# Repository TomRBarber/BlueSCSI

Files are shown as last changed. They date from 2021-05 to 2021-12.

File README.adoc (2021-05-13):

# BlueSCSI
:toc: macro

BlueSCSI & ArdSCSino are hardware that reproduces SCSI devices (hard disks) with an Arduino STM32F103C (aka Blue Pill.)

`BlueSCSI` created by https://github.com/erichelgeson[erichelgeson] is a fork of `ArdSCSino-stm32` which adds:

* Usability Improvements
* Mac specific functionality
* Enable/Disable Passive SCSI termination
* An alternative power source if not able to be powered by the SCSI bus
* Documentation
* Open Hardware (KiCad & Grebers)

`ArdSCSino-stm32` created by https://github.com/ztto/ArdSCSino-stm32[ztto] is the STM32 version of `ArdSCSino`

`ArdSCSino` created by https://twitter.com/h_koma2[Tambo (TNB Seisakusho)]




Join us in #bluescsi on https://discord.gg/GKcvtgU7P9[Discord] or open an issue on this repo.

toc::[]

## Compatibility

If your computer is not listed below - it may be compatible but there is no guarantee it will work. This device is designed and tested to work with pre-PowerPC Macs.

### Compatible

#### Tested by Me

SE, SE/30, Classic, Classic II, Mac II's, Color Classic, LC I/II/III, LC 475, LC 575

#### Partially Compatible

Mac Plus (1.0-c and above) - Only System 7 currenty works.

PowerPC - Some have had luck booting but is not recommended.

#### Reported by others

https://68kmla.org/forums/topic/61045-arduino-scsi-device-work-in-progress/?do=findComment&comment=663077[IIcx], https://68kmla.org/forums/topic/61045-arduino-scsi-device-work-in-progress/?do=findComment&comment=664446[PowerBook 100 (with custom adapter)]

## Performance

Tested on a Color Classic with https://macintoshgarden.org/apps/scsi-director-pro-40[SCSI Director Pro 4]
```
1024KB/Sec Write
900KB/Sec Read
1.01ms Seek
```

## Assembly

++++
See <a href="docs/assembly.md">docs/assembly.md</a>
++++

## Usage

Hard Disk image files are placed in the root directory of a `ExFat` or `FAT32` formatted SD card. https://twitter.com/theory_retro/status/1376571371694723076[`ExFat` may be much faster]. Use a premade or blank disk below. These images are compatible with the RaSCSI device and Basilisk II emulator.

The naming convention is as follows (file name max 32 characters). Note you may mount multiple drives at a time to different SCSI ID's.

`HDxy_512.hda`
```
HD - Hard Disk
x - SCSI ID to attach to. 0-7 (though 7 on a Macintosh is the System)
y - LUN id usually 0. 
512 - Sector size. Usually 512. 256, 512, & 1024 supported.
```

### Examples

`HD10_512.hda` - Hard Disk at SCSI ID 1, LUN 0, sector size of 512.

`HD51_512 System 6.0.8L LC.hda` - Hard Disk at SCSI ID 5, LUN 1, sector size of 512. Text between block size and .hda is ignored.

#### Bad 

`HD99_712 foo bar fizz buzz bang.hda` Over 32 chars and invalid SCSI/LUN/Block size

If no image files are found PC13 will pulse on and off. Check the LOG.txt on the root of the SD card for any errors.

### Premade Images

Premade images are handy to just drop onto your SD card and go. You can use an emulator such as https://www.emaculation.com/doku.php/basiliskii_osx_setup[Basilisk II] on your modern machine to get software from places like the https://macintoshgarden.com[Macintosh Garden] to your vintage mac.

* Premade from RaSCSI in BlueSCSI too - Rename the files based on the Usage instructions above. - http://macintoshgarden.org/apps/rascsi-68kmla-edition

### Blanks

These are blank, formatted drives. If you want to install an OS or software on an empty drive, use one of these.

* Preformatted HFS blank images in various sizes - https://github.com/erichelgeson/BlueSCSI/tree/main/docs/MacHD.zip

### Custom Disk Images (Advanced)

This technique is useful when you would like a disk image larger than the pre-built images in the previous section.

The following instructions demonstrates the process using https://ss64.com/osx/dd.html[dd] on a modern Mac:

1. Open terminal.
2. The following command will create a blank disk image. You can modify the command to suit your use.
   * `dd if=/dev/zero of=example.hda bs=1m count=500`
   * The `count` field defines the number of megabytes (`bs=1m`) the total disk image should be.
   * The output file from the command is "example.hda". This can be changed in the `of=example.hda` field.
3. Place the new blank disk image in the root directory of your SD card.
4. If you do not already have a tool to format SCSI drives, https://macintoshgarden.org/apps/lido-756[download LIDO]. You can use an emulator such as https://www.emaculation.com/doku.php/basiliskii_osx_setup[Basilisk II] to move files to the image to prepare your installation.
5. After booting into your target machine with the working Mac OS disk image on your BlueSCSI from step 3, format the blank disk.

### Termination

To enable termination place the two jumpers on the TERM block. Termination should be enabled if it is the last device in the SCSI chain, otherwise remove the jumpers if it is not.

## Troubleshooting

If you assembled it yourself, either through a kit or by sourcing the parts yourself, link:docs/troubleshooting-Kit.adoc[start here]

If you purchased a pre-assembled kit, or have already gone through the hardware troubleshooting steps, link:docs/troubleshooting-assembled.adoc[start here]

## Hardware Versions

### 1.1-a (in testing)

* Other SCSI connection types
* More silk screen art

### 1.0-c (Latest)

* Fixed issue with diode footprint being too small
* Fixed issue with external power and `TERMPOWER`

### 1.0-b

First release

## Development (Advanced)

Below is for users who wish to edit or develop on the BluePill - normal users should not need to worry about this.

### Setup PlatformIO IDE

Open the project in https://platformio.org/platformio-ide[PlatformIO IDE] and everything is pre-configured.

## Flashing

When flashing you have two options:

Flash by setting up the IDE and re-compiling and programming. If you are a developer and plan to contribute this method is what you should use.

You may also flash the `.bin` file directly from https://www.st.com/en/development-tools/stm32cubeprog.html[STM32CubeProgrammer]. Use this method if you are not a developer and just wish to get the code to the BluePill.

### Using STLink v2 (prefered)

1. Remove SD Card
2. Make sure the STLink is up to date - https://www.st.com/en/development-tools/stsw-link007.html[Latest Firmware]
3. Connect pins `SWDIO`(2), `GND`(4), `SWCLK`(6), and `3.3v`(8) from the programmer to the Blue Pill. NOTE: These are not the same as Serial ports.
4. Run the https://docs.platformio.org/en/latest/integration/ide/vscode.html#project-tasks[PlatformIO: Upload] task.
5. You should see the LED `PC_13` flashing indicating no SD Card detected.
6. Insert SD Card, boot on your favorite Mac!

The following YoutTube video demonstrates the steps of flashing & updating your BlueSCSI https://www.youtube.com/watch?v=bRLAOts_MTM

#### Trouble Shooting

If the device is not detected you may need to hold reset, click program, once it is detected release reset.

If you are unable to get the device in DFU mode for programming you may need to use https://www.st.com/en/development-tools/stm32cubeprog.html[STM32CubeProgrammer] to erase the chip.

### Alterantive upload methods

See the https://docs.platformio.org/en/latest/boards/ststm32/bluepill_f103c8.html#uploading[uploading] documentation on PlatformIO for alterantives.

### Using USB HID

Note: I have not been able to get this method to work. Please contribute to this document if you do.

## Notes

### Making Gerbers for JLCPCB

https://support.jlcpcb.com/article/44-how-to-export-kicad-pcb-to-gerber-files

BlueSCSI(TM) - Eric Helgeson - All rights reserved.

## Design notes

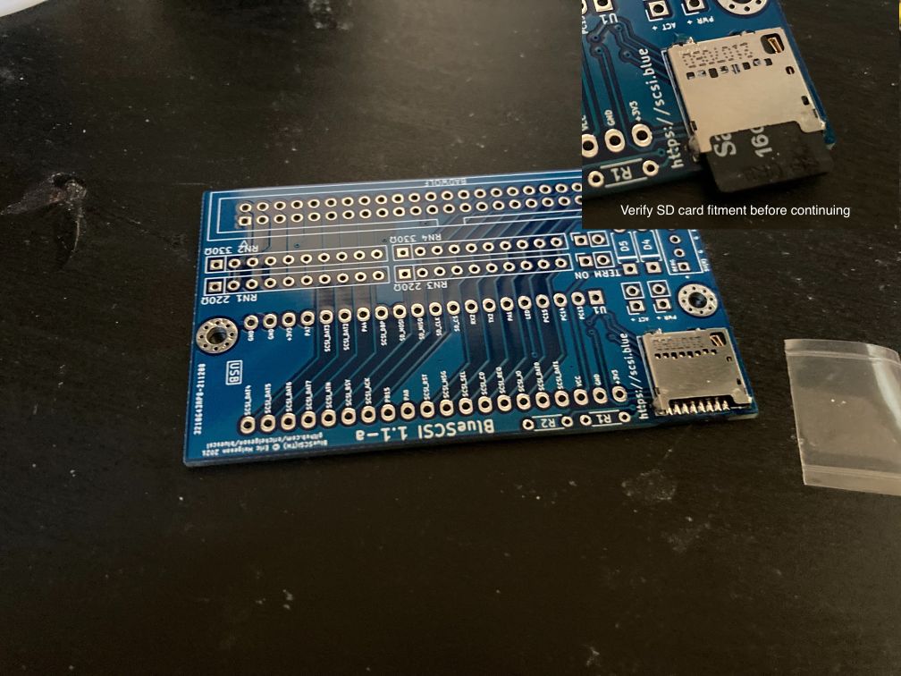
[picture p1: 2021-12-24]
docs/images/DesktopSDSlot.jpg

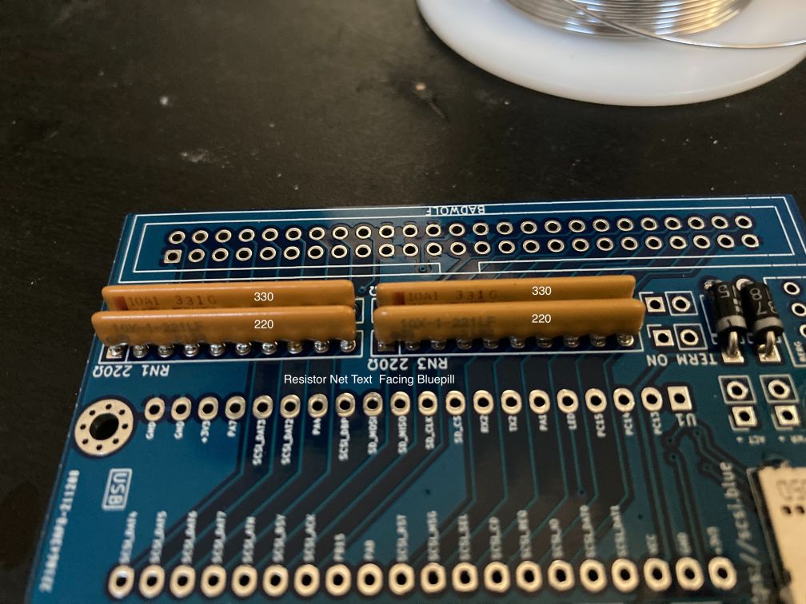
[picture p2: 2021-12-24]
docs/images/DesktopOrientation.jpg

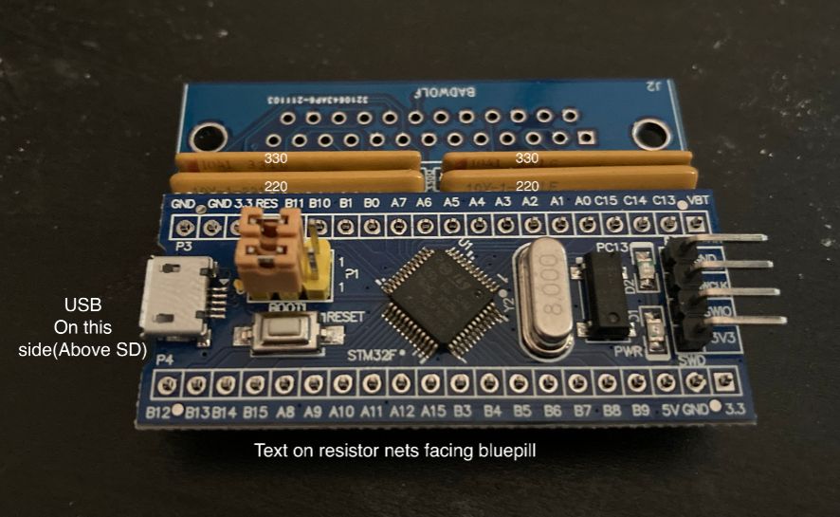
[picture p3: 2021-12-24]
docs/images/DB25-Orientation.jpg

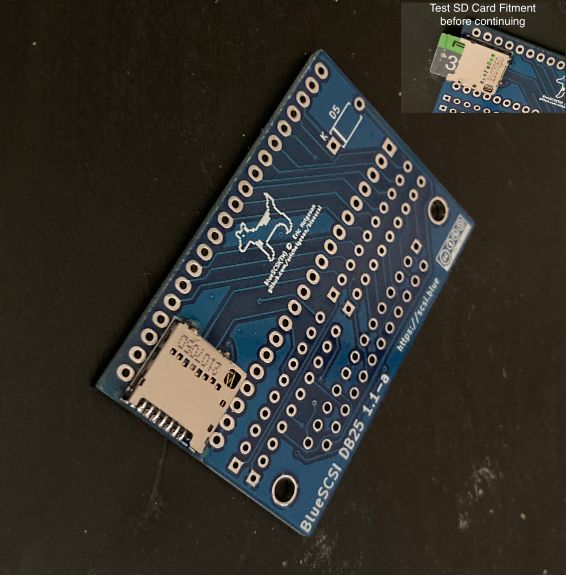
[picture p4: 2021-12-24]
docs/images/DB25 SD Slot.jpg

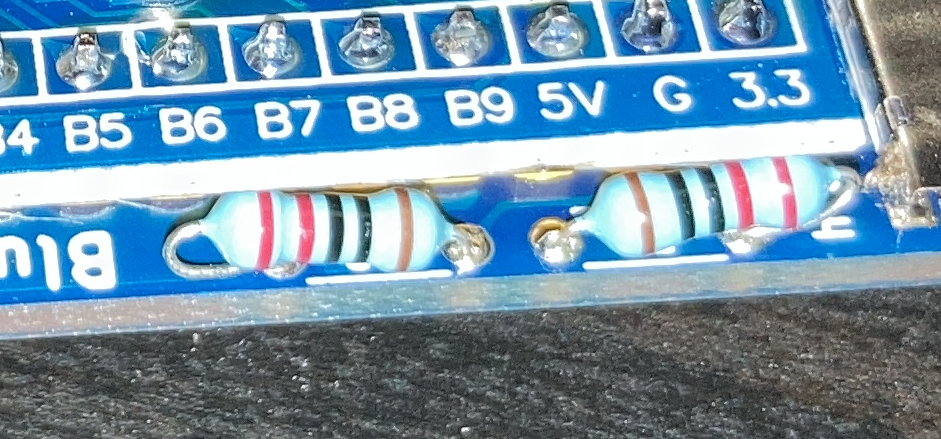
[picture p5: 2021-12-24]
docs/images/DesktopResistorFitment.png

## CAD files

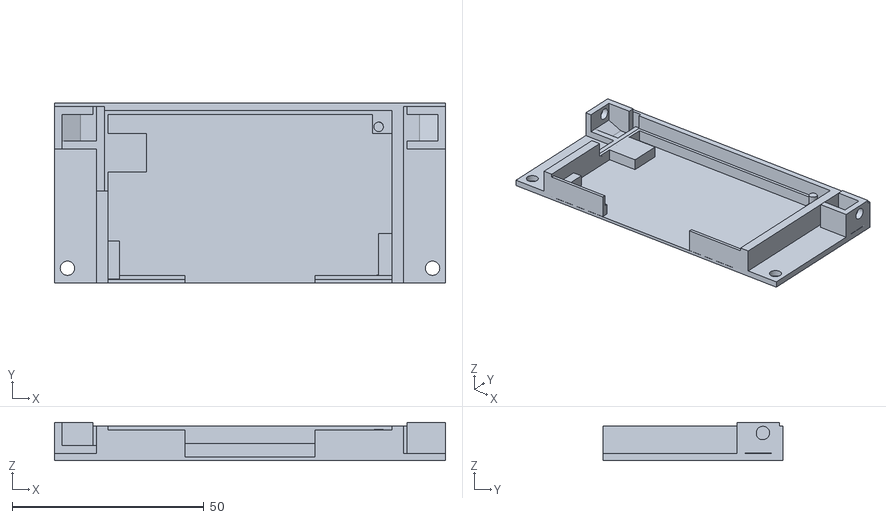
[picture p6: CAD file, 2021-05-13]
3D-Files/bluescsibracket-2.stl
102.0 x 47.0 x 10.0

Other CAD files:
3D-Files/BlueSCSI-1.0-b_V3.stl

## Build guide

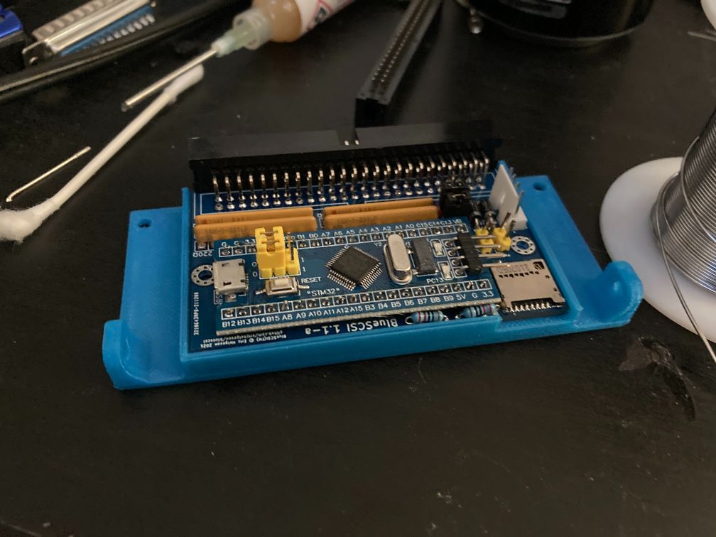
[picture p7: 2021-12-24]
docs/images/DesktopASsembledInCase.jpg

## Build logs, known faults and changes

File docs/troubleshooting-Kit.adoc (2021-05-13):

# Troubleshooting(Kit)

## General:

  * Do not adjust any jumpers on the BluePill microcontroller itself(the 2 near the USB port).  Those are used for programming the device and can potentially erase the memory

  * Double check solder connections.  Ensure no solder bridges, cold or broken solder joints, bad solder connections, etc.  If in doubt, can’t hurt to touch it up.

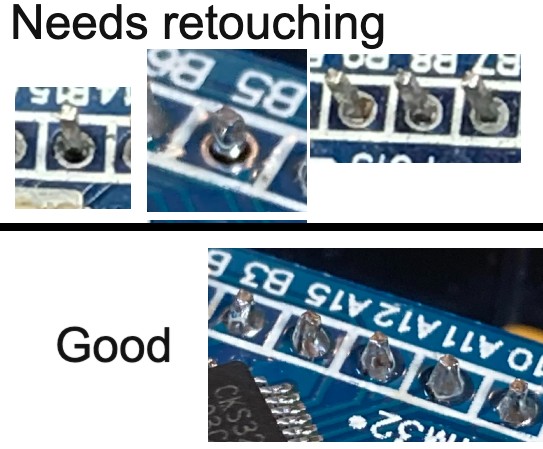
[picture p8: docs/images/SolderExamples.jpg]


  * Make sure Resistor networks are facing the correct way, and the Bluepill is inserted onto the board with the USB next to the SD.



  * Check the chip on the Bluepill itself, make sure no solder balls or anything(If there are, sometimes you can just knock them off with a small screwdriver or toothpick, sometimes you'll need to use an iron and flux/wick)
  


  * Clean any excess flux on the board,  even if it says no-clean.  Sometimes that can cause issues.  Rubbing alcohol and a toothbrush is usually a good solution.

  * Make sure your termination is set correctly.  If it’s the last device on the SCSI chain, you must have termination enabled by having the 2 jumpers on the BlueSCSI board near the SCSI port and resistor networks.

  * Make sure there are no conflicting SCSI IDs. If possible, remove any other SCSI devices.

  * If you have another computer to try it on, give it a try on there.

## No Power:
Most computers should provide SCSI termination power through the SCSI cable, which is enough to power the Bluepill(Mac Plus is a known exception unless you do a mod), but it’s entirely possible a computer doesn’t for whatever reason.   Unplug the BlueSCSI from the computer’s SCSI Connection and try to power it either through the MicroUSB port on the BluePill, or 5v through the Berg connector.  If it lights up at all, it’s possible you computer doesn’t provide the correct SCSI termination power.  Double check all your solder joints on the BluePill, SCSI connector, and Resistor networks.  If those are good, you can get a cheap Molex to Floppy(Berg) power connector and use it that way.

Also ensure that nothing on the BlueSCSI has been shorted out at all.  Any time you’re working on it make sure any headers from components aren’t resting on a conductive surface.

## PC13 LED flashes 5x
This means the SD card cannot be found

  * Check the connections in the MicroSD Socket.  Make sure they all look covered with solder, no bridges between contacts, etc
  * Make sure that the outside of the shield is properly soldered down

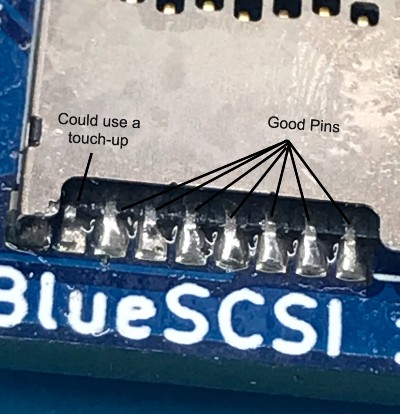
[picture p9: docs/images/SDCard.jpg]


  * With a multimeter in continuity mode, check the following pins on the SD card slot, make sure they contact the pins correct pins on the bluepill.  

|=======================
|SD Socket|BluePill 
|1    |N/C
|2    |A6 
|3    |Gnd
|4    |A5
|5    |3.3V
|6    |A7
|7    |A4
|8    |N/C
|=======================

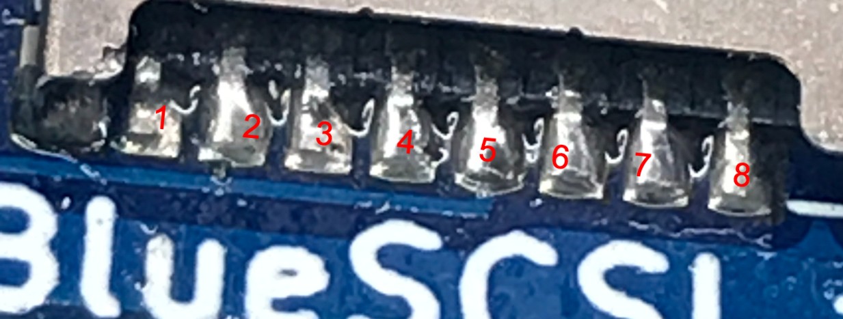
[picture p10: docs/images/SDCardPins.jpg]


  * Make sure no 2 pins are shorting against each other. 
  * Make sure all Flux is cleaned off the board, a toothbrush with rubbing alcohol on it tends to work well.
  * SD Cards need to be either ExFAT or Fat32 formatted(ExFAT gives better performance).  They must be using MBR, not GPT or Apple partition scheme.  
  * The tool on https://www.sdcard.org/downloads/formatter/ tends to work well for resolving formatting issues.  Chose the “Overwrite format” option.
  * If you have another SD card, give that a try.

## PC13 continuously flashes
This could be 2 things.  If it’s running an older version of the BlueSCSI software, that means no SD card found or an image can’t be loaded.  Follow the steps in Troubleshooting-Assembled

It could also mean that it’s running the default “blink” program that often comes loaded on BluePills. If you messed with the jumpers on the BluePill itself, make sure they are both set to the 0 position(Closest to the MicroUSB port).  If you purchased the BluePill yourself, make sure you flashed the software using the https://github.com/erichelgeson/BlueSCSI#flashing[flashing procedure].   
If you purchased the kit from an authorized BlueSCSI distributor, it should come pre-flashed with the latest software.  Contact who you bought it from.  

## Further troubleshooting

If the troubleshooting above doesn’t work, or there’s another issue, check the link:troubleshooting-assembled.adoc[Troubleshooting-Assembled] document

You can also join us on Discord and ask in the BlueSCSI-support channel.  It has many contributors of the BlueSCSI project and knowledgable BlueSCSI users

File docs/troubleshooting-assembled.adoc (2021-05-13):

# Troubleshooting(Pre-Assembled)

## General:

  * Do not adjust any jumpers on the BluePill microcontroller itself(the 2 near the USB port).  Those are used for programming the device and can potentially erase the memory

  * If you purchased a kit, first go through the link:troubleshooting-Kit.adoc[Troubleshooting-Kit] document to ensure everything is right with your hardware

 * Remove the SD card, power it just through MicroUSB or the Berg connector.  It should flash 5x which means no SD card found.  If it doesn’t, that means there’s another problem

  * Make sure your termination is set correctly.  If it’s the last device on the SCSI chain, you must have termination enabled by having the 2 jumpers on the BlueSCSI board near the SCSI port and resistor networks.

  * Make sure there are no conflicting SCSI IDs. If possible, remove any other SCSI devices.

  * If you have another computer to try it on, give it a try on there.

## No Power:
Most computers should provide SCSI termination power through the SCSI cable, which is enough to power the Bluepill(Mac Plus is a known exception unless you do a mod), but it’s entirely possible a computer doesn’t for whatever reason.   Unplug the BlueSCSI from the computer’s SCSI Connection and try to power it either through the MicroUSB port on the BluePill, or 5v through the Berg connector.  If it lights up at all, it’s possible you computer doesn’t provide the correct SCSI termination power.  If that's the case, you can get a cheap Molex to Floppy(Berg) power connector and use it that way, or power it through USB

Also ensure that nothing on the BlueSCSI has been shorted out at all.  Any time you’re working on it make sure any headers from components aren’t resting on a conductive surface.

## PC13 LED flashes 3x
This means that no images could be found.

  * Ensure images are named correctly, such as HD10_512.hda .  Verify that there are no hidden file extensions(Windows and Mac OS like to hide file extensions by default).  Ensure its’s not really HD10_512.hda.img for example

  * Use one of the pre-made images on Macintosh Garden - https://macintoshgarden.org/apps/bluescsi

  * Check the LOG.txt file on the root of the SD card, that will show specific details about what the BlueSCSI tried to do

## PC13 LED flashes 5x
This means the SD card cannot be found

  * SD Cards need to be either ExFAT or Fat32 formatted(ExFAT gives better performance).  They must be using MBR, not GPT or Apple partition scheme.  
  * The tool on https://www.sdcard.org/downloads/formatter/ tends to work well for resolving formatting issues.  Chose the “Overwrite format” option.
  * If you have another SD card, give that a try.

## PC13 continuously flashes
This could be 2 things.  If it’s running an older version of the BlueSCSI software, that means no SD card found or an image can’t be loaded.  Follow all the troubleshooting steps in the above sections.

It could also mean that it’s running the default “blink” program that often comes loaded on BluePills. If you messed with the jumpers on the BluePill itself, make sure they are both set to the 0 position(Closest to the MicroUSB port).  If you purchased the BluePill yourself, make sure you flashed the software using the https://github.com/erichelgeson/BlueSCSI#flashing[flashing procedure].   
If you purchased a assembled unit or a kit from someone, it should come pre-flashed with the latest software.  Contact who you bought it from.  

## Slow performance

  * Ensure you are using a good SD card. SD card quality can vary widely. 

  * Format your card as ExFat - users have seen quite a jump in performance.

## Further troubleshooting

If the troubleshooting above doesn’t work, or there’s another issue.  Join us on Discord and ask in the BlueSCSI-support channel.  It has many contributors of the BlueSCSI project and knowledgable BlueSCSI users

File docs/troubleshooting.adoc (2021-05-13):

# Troubleshooting BlueSCSI

If you assembled it yourself, either through a kit or by sourcing the parts yourself, link:troubleshooting-Kit.adoc[start here]

If you purchased a pre-assembled kit, or have already gone through the hardware troubleshooting steps, link:troubleshooting-assembled.adoc[start here]
